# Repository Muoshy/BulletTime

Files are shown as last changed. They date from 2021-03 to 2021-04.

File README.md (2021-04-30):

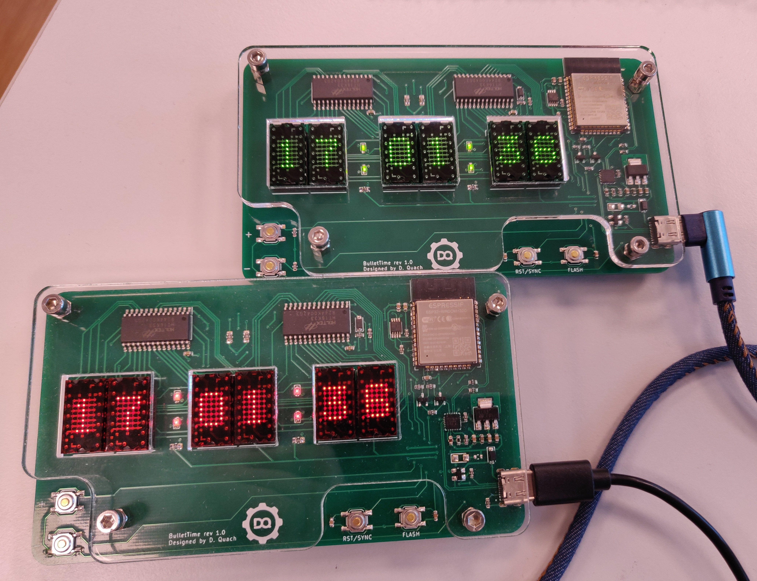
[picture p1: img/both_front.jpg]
top


# BulletTime
ESP32 based clock using LTP-305 led matrices.

	- NTP time retrieval
	- Brightness control
	- esp-idf
	- USB-C

## Schematic
WIP

## PCB
WIP

## Acrylic cover
WIP

## Software
Running esp-idf with esp32-wifi-manager 3.3.1 by tonyp7 for setting wifi credentials during runtime. 
Time set using sntp time example from esp-idf repository.
Brightness control using button interrupts.

## Flashing
	- Install esp-idf extension from Visual Studio Code marketplace
	- Open LTP_clock folder from VSCode
	- Select port, compile & flash.

## BOM

| Component 		| Quantity 	| Description 						|
|---		|---	|---								|
| ESP32-WROOM-32D 	| 1x 		| ESP32 						|
| CP2102N-A02-GQFN24 | 1x 	| USB-UART 						|
| HT16K33			| 2x		| LED driver |
| LDL1117 			| 1x 	| Voltage regulator 			|
| SP0503BAHTG				 	| 1x 	| ESD-protection 				|
| LTP-305					 	| 6x 	| 5x7 led matrix 				|
| PCA9306					 	| 1x 	| I2C level shifter 			|
| 5.2x5.2mm SMD pushbutton 		| 4x 	| Pushbutton						|
| 14 Position DIP socket | 6x 	| 								|
| Resistors (WIP) 		| 	| 								|
| Capacitors (WIP) 		| 	| 								|

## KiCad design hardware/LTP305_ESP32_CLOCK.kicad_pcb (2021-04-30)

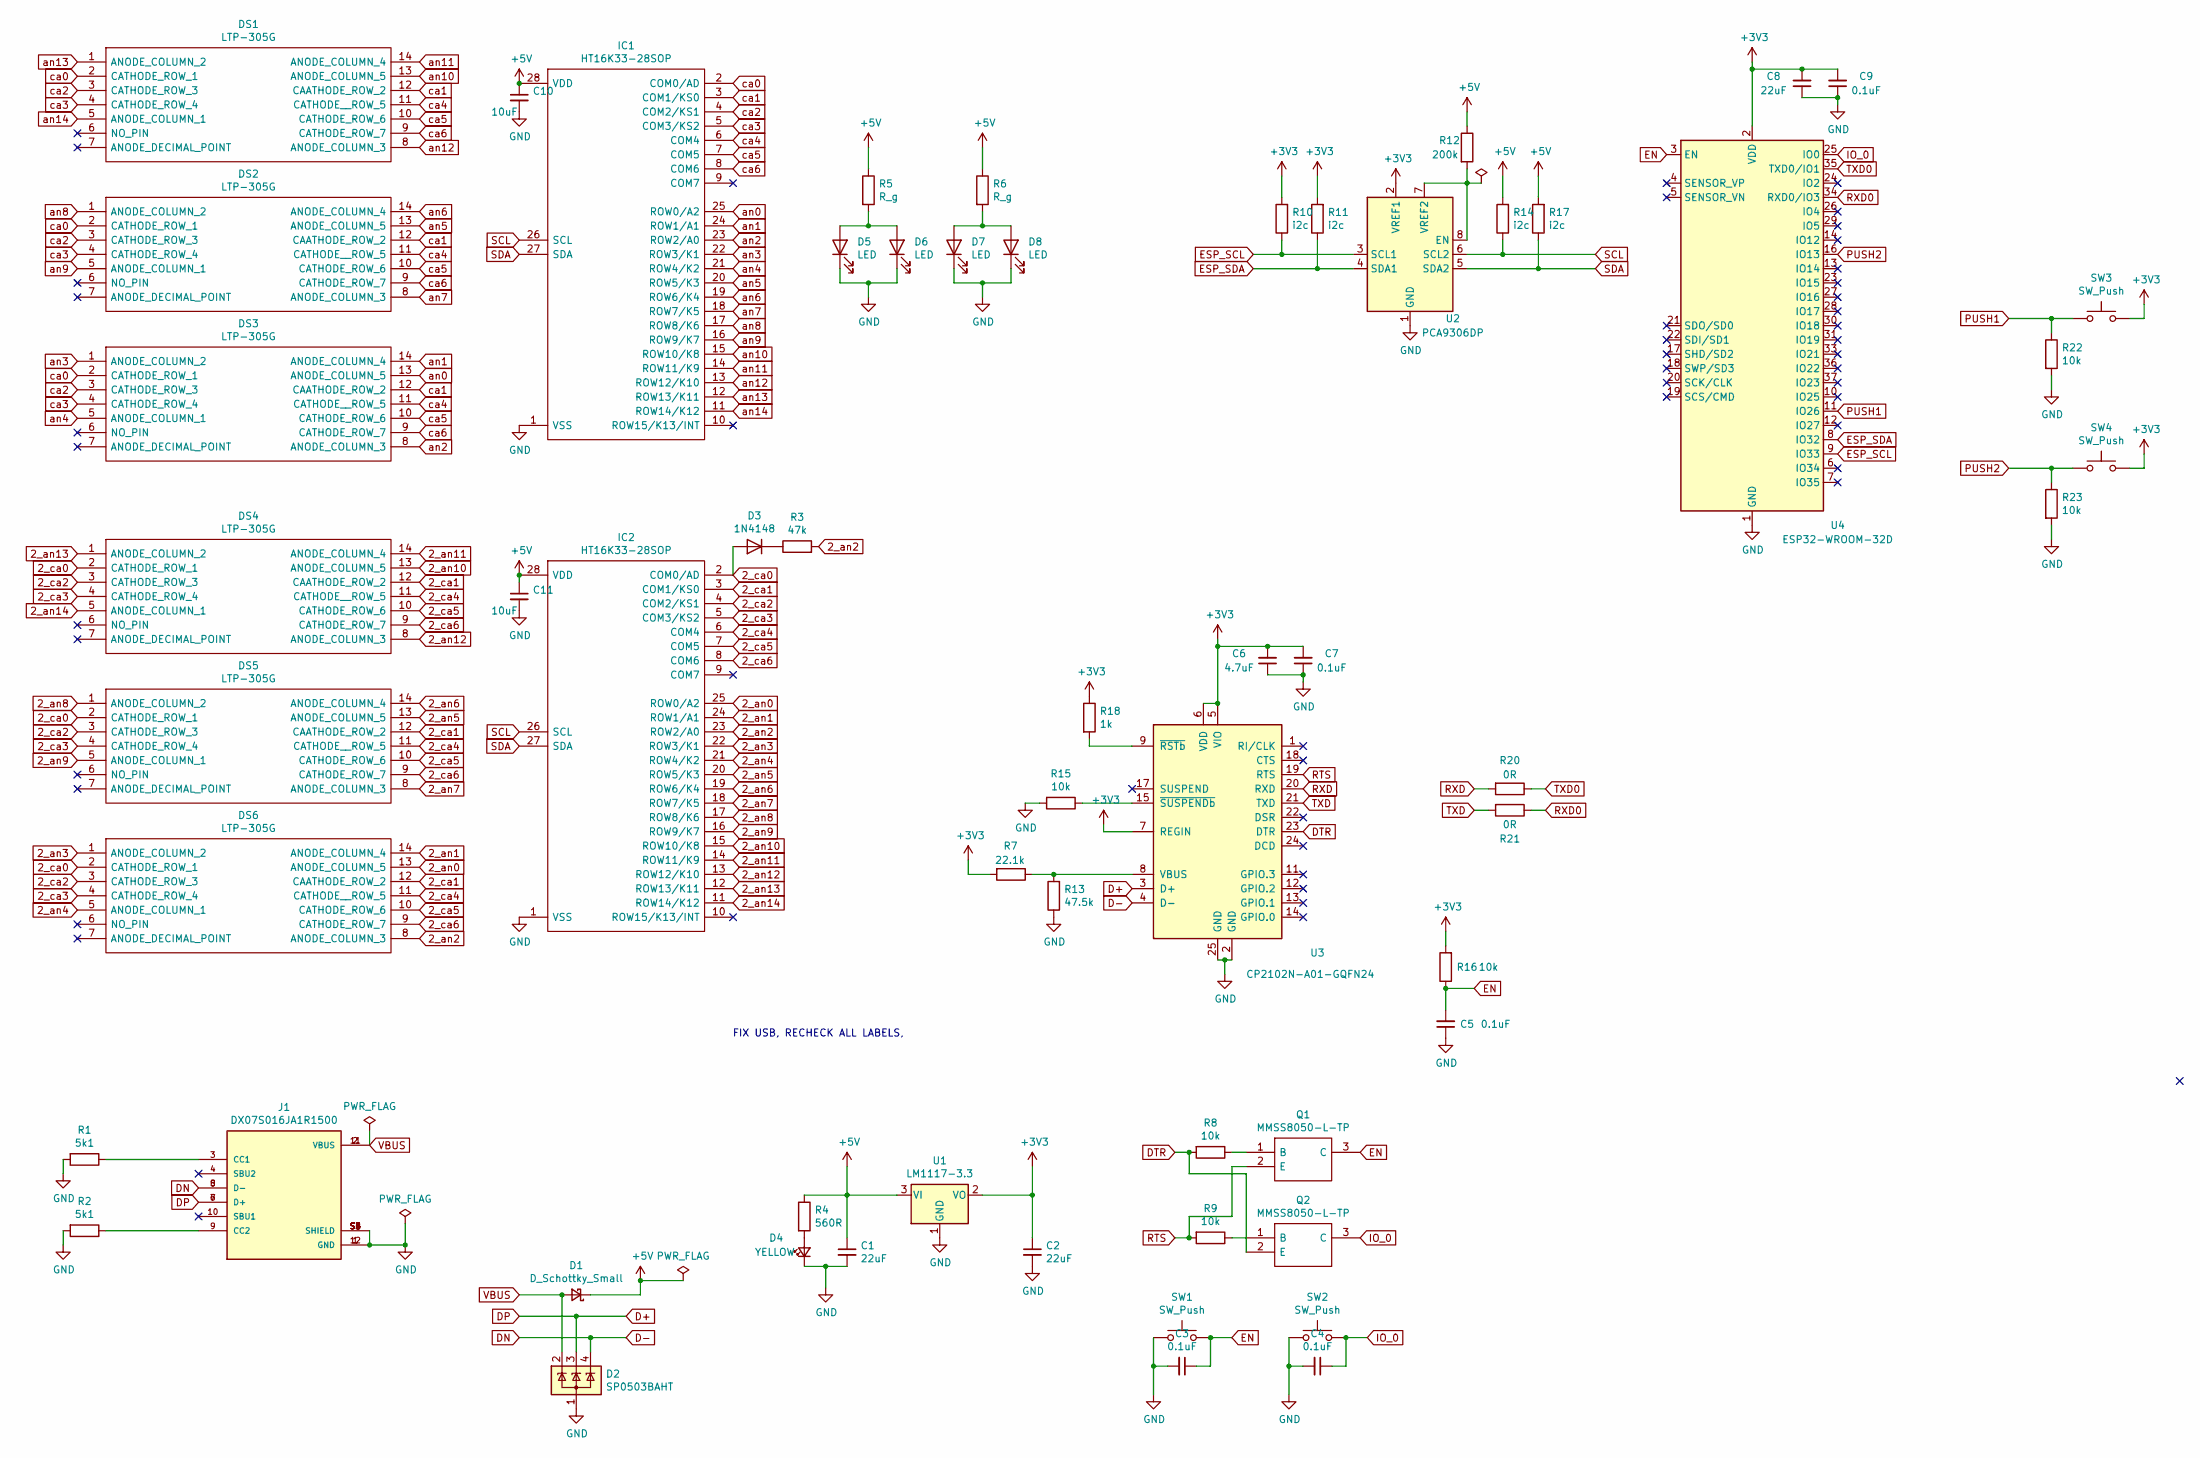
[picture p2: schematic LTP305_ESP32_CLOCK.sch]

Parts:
C1, C2, C8: 22uF; C_0603_1608Metric
C3, C4, C5, C7, C9: 0.1uF; C_0603_1608Metric
C6: 4.7uF; C_0603_1608Metric
C10, C11: 10uF; C_0603_1608Metric
D1: D_Schottky_Small; D_SOD-123
D2: SP0503BAHT; SOT-143
D3: 1N4148; D_SOD-123
D4: YELLOW; LED_1206_3216Metric_Castellated
D5, D6, D7, D8: LED; LED_0603_1608Metric_Pad1.05x0.95mm_HandSolder
DS1, DS2, DS3, DS4, DS5, DS6: LTP-305G; DIPS762W50P254L1850H400Q14N; Mouser Part Number 859-LTP-305G
IC1, IC2: HT16K33-28SOP; SOIC127P1031X264-28N; Manufacturer_Part_Number HT16K33-28SOP
J1: DX07S016JA1R1500; JAE_DX07S016JA1R1500; PARTREV 1
Q1, Q2: MMSS8050-L-TP; SOT96P237X122-3N; Mouser Part Number 833-MMSS8050-L-TP
R1, R2: 5k1; R_0603_1608Metric
R3: 47k; R_0603_1608Metric
R4: 560R; R_0603_1608Metric
R5, R6: R_g; R_0805_2012Metric_Pad1.20x1.40mm_HandSolder
R7: 22.1k; R_0603_1608Metric
R8, R9, R15, R16, R22, R23: 10k; R_0603_1608Metric
R10, R11: i2c; R_0603_1608Metric
R12: 200k; R_0603_1608Metric
R13: 47.5k; R_0603_1608Metric
R14, R17: i2c; R_0805_2012Metric_Pad1.20x1.40mm_HandSolder
R18: 1k; R_0603_1608Metric
R20, R21: 0R; R_0603_1608Metric
SW1, SW2, SW3, SW4: SW_Push; SW_SPST_SKQG_WithStem
U1: LM1117-3.3; SOT-223
U2: PCA9306DP; TSSOP-8_3x3mm_P0.65mm
U3: CP2102N-A01-GQFN24; QFN-24-1EP_4x4mm_P0.5mm_EP2.6x2.6mm
U4: ESP32-WROOM-32D; ESP32-WROOM-32

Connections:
2_an0: DS6.13 (ANODE_COLUMN_5), IC2.25 (ROW0/A2)
2_an1: DS6.14 (ANODE_COLUMN_4), IC2.24 (ROW1/A1)
2_an2: DS6.8 (ANODE_COLUMN_3), IC2.23 (ROW2/A0), R3.2
2_an3: DS6.1 (ANODE_COLUMN_2), IC2.22 (ROW3/K1)
2_an4: DS6.5 (ANODE_COLUMN_1), IC2.21 (ROW4/K2)
2_an5: DS5.13 (ANODE_COLUMN_5), IC2.20 (ROW5/K3)
2_an6: DS5.14 (ANODE_COLUMN_4), IC2.19 (ROW6/K4)
2_an7: DS5.8 (ANODE_COLUMN_3), IC2.18 (ROW7/K5)
2_an8: DS5.1 (ANODE_COLUMN_2), IC2.17 (ROW8/K6)
2_an9: DS5.5 (ANODE_COLUMN_1), IC2.16 (ROW9/K7)
2_an10: DS4.13 (ANODE_COLUMN_5), IC2.15 (ROW10/K8)
2_an11: DS4.14 (ANODE_COLUMN_4), IC2.14 (ROW11/K9)
2_an12: DS4.8 (ANODE_COLUMN_3), IC2.13 (ROW12/K10)
2_an13: DS4.1 (ANODE_COLUMN_2), IC2.12 (ROW13/K11)
2_an14: DS4.5 (ANODE_COLUMN_1), IC2.11 (ROW14/K12)
2_ca0: D3.2 (A), DS4.2 (CATHODE_ROW_1), DS5.2 (CATHODE_ROW_1), DS6.2 (CATHODE_ROW_1), IC2.2 (COM0/AD)
2_ca1: DS4.12 (CAATHODE_ROW_2), DS5.12 (CAATHODE_ROW_2), DS6.12 (CAATHODE_ROW_2), IC2.3 (COM1/KS0)
2_ca2: DS4.3 (CATHODE_ROW_3), DS5.3 (CATHODE_ROW_3), DS6.3 (CATHODE_ROW_3), IC2.4 (COM2/KS1)
2_ca3: DS4.4 (CATHODE_ROW_4), DS5.4 (CATHODE_ROW_4), DS6.4 (CATHODE_ROW_4), IC2.5 (COM3/KS2)
2_ca4: DS4.11 (CATHODE__ROW_5), DS5.11 (CATHODE__ROW_5), DS6.11 (CATHODE__ROW_5), IC2.6 (COM4)
2_ca5: DS4.10 (CATHODE_ROW_6), DS5.10 (CATHODE_ROW_6), DS6.10 (CATHODE_ROW_6), IC2.7 (COM5)
2_ca6: DS4.9 (CATHODE_ROW_7), DS5.9 (CATHODE_ROW_7), DS6.9 (CATHODE_ROW_7), IC2.8 (COM6)
+3V3: C2.1, C6.2, C7.2, C8.2, C9.2, R7.2, R10.2, R11.2, R16.2, R18.1, SW3.2, SW4.2, U1.2 (VO), U1.4, U2.2 (VREF1), U3.5 (VIO), U3.6 (VDD), U3.7 (REGIN), U4.2 (VDD); also elsewhere on the board
+5V: C1.1, C10.1, C11.1, D1.1 (K), IC1.28 (VDD), IC2.28 (VDD), R4.1, R5.1, R6.1, R12.1, R14.2, R17.2, U1.3 (VI)
D+: D2.3 (K), J1.6 (D+), J1.7 (D+), U3.3 (D+)
D-: D2.4 (K), J1.5 (D-), J1.8 (D-), U3.4 (D-)
DTR: Q2.2 (E), R8.2, U3.23 (DTR)
EN: C3.1, C5.2, Q1.3 (C), R16.1, SW1.2, U4.3 (EN); also elsewhere on the board
ESP_SCL: R10.1, U2.3 (SCL1), U4.9 (IO33)
ESP_SDA: R11.1, U2.4 (SDA1), U4.8 (IO32)
GND: C1.2, C2.2, C3.2, C4.2, C5.1, C6.1, C7.1, C8.1, C9.1, C10.2, C11.2, D2.1 (A), D4.1 (K), D5.1 (K), D6.1 (K), D7.1 (K), D8.1 (K), IC1.1 (VSS), IC2.1 (VSS), J1.1 (GND), J1.12 (GND), J1.S1 (SHIELD), J1.S2 (SHIELD), J1.S3 (SHIELD), J1.S4 (SHIELD), J1.S5 (SHIELD), J1.S6 (SHIELD), R1.2, R2.2, R13.1, R15.2, R22.2, R23.2, SW1.1, SW2.1, U1.1 (GND), U2.1 (GND), U3.2 (GND), U3.25 (GND), U4.1 (GND), U4.15 (GND), U4.38 (GND), U4.39 (GND); also elsewhere on the board
IO_0: C4.1, Q2.3 (C), SW2.2, U4.25 (IO0); also elsewhere on the board
unnamed: D3.1 (K), R3.1
unnamed: D4.2 (A), R4.2
unnamed: D5.2 (A), D6.2 (A), R5.2
unnamed: D7.2 (A), D8.2 (A), R6.2
unnamed: J1.3 (CC1), R1.1
unnamed: J1.9 (CC2), R2.1
unnamed: Q1.1 (B), R8.1
unnamed: Q2.1 (B), R9.1
unnamed: R12.2, U2.7 (VREF2), U2.8 (EN)
unnamed: R7.1, R13.2, U3.8 (VBUS)
unnamed: R15.1, U3.15 (~SUSPENDb)
unnamed: R18.2, U3.9 (~RSTb)
PUSH1: R22.1, SW3.1, U4.11 (IO26); also elsewhere on the board
PUSH2: R23.1, SW4.1, U4.16 (IO13); also elsewhere on the board
RTS: Q1.2 (E), R9.2, U3.19 (RTS)
RXD: R20.2, U3.20 (RXD)
RXD0: R21.1, U4.34 (RXD0/IO3)
SCL: IC1.26 (SCL), IC2.26 (SCL), R14.1, U2.6 (SCL2)
SDA: IC1.27 (SDA), IC2.27 (SDA), R17.1, U2.5 (SDA2)
TXD: R21.2, U3.21 (TXD)
TXD0: R20.1, U4.35 (TXD0/IO1)
VBUS: D1.2 (A), D2.2 (K), J1.2 (VBUS), J1.11 (VBUS)
an0: DS3.13 (ANODE_COLUMN_5), IC1.25 (ROW0/A2)
an1: DS3.14 (ANODE_COLUMN_4), IC1.24 (ROW1/A1)
an2: DS3.8 (ANODE_COLUMN_3), IC1.23 (ROW2/A0)
an3: DS3.1 (ANODE_COLUMN_2), IC1.22 (ROW3/K1)
an4: DS3.5 (ANODE_COLUMN_1), IC1.21 (ROW4/K2)
an5: DS2.13 (ANODE_COLUMN_5), IC1.20 (ROW5/K3)
an6: DS2.14 (ANODE_COLUMN_4), IC1.19 (ROW6/K4)
an7: DS2.8 (ANODE_COLUMN_3), IC1.18 (ROW7/K5)
an8: DS2.1 (ANODE_COLUMN_2), IC1.17 (ROW8/K6)
an9: DS2.5 (ANODE_COLUMN_1), IC1.16 (ROW9/K7)
an10: DS1.13 (ANODE_COLUMN_5), IC1.15 (ROW10/K8)
an11: DS1.14 (ANODE_COLUMN_4), IC1.14 (ROW11/K9)
an12: DS1.8 (ANODE_COLUMN_3), IC1.13 (ROW12/K10)
an13: DS1.1 (ANODE_COLUMN_2), IC1.12 (ROW13/K11)
an14: DS1.5 (ANODE_COLUMN_1), IC1.11 (ROW14/K12)
ca0: DS1.2 (CATHODE_ROW_1), DS2.2 (CATHODE_ROW_1), DS3.2 (CATHODE_ROW_1), IC1.2 (COM0/AD)
ca1: DS1.12 (CAATHODE_ROW_2), DS2.12 (CAATHODE_ROW_2), DS3.12 (CAATHODE_ROW_2), IC1.3 (COM1/KS0)
ca2: DS1.3 (CATHODE_ROW_3), DS2.3 (CATHODE_ROW_3), DS3.3 (CATHODE_ROW_3), IC1.4 (COM2/KS1)
ca3: DS1.4 (CATHODE_ROW_4), DS2.4 (CATHODE_ROW_4), DS3.4 (CATHODE_ROW_4), IC1.5 (COM3/KS2)
ca4: DS1.11 (CATHODE__ROW_5), DS2.11 (CATHODE__ROW_5), DS3.11 (CATHODE__ROW_5), IC1.6 (COM4)
ca5: DS1.10 (CATHODE_ROW_6), DS2.10 (CATHODE_ROW_6), DS3.10 (CATHODE_ROW_6), IC1.7 (COM5)
ca6: DS1.9 (CATHODE_ROW_7), DS2.9 (CATHODE_ROW_7), DS3.9 (CATHODE_ROW_7), IC1.8 (COM6)

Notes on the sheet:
FIX USB, RECHECK ALL LABELS,

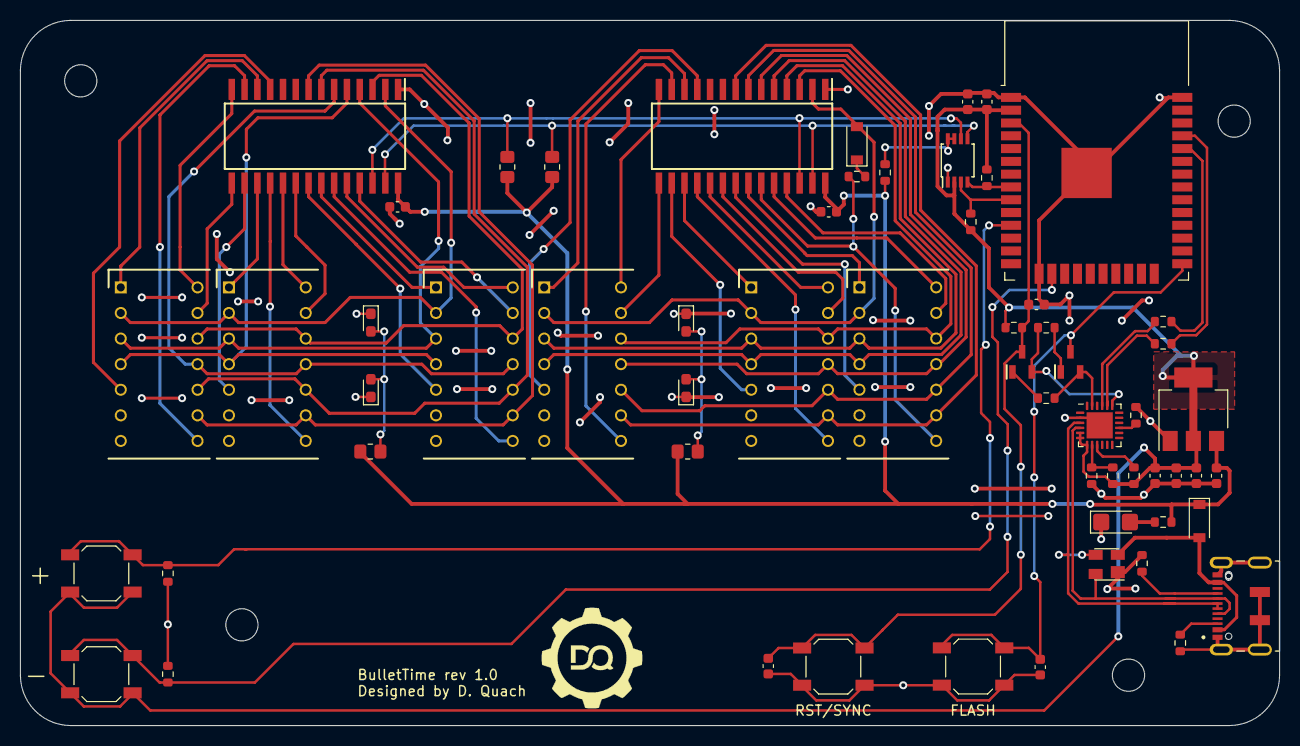
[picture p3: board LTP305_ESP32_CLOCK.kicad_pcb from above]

Board: 2 copper layers, 125.0 x 70.0 mm, 60 parts (0 on the bottom side), 76 nets.

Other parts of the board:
+: SW_Push; SW_SPST_SKQG_WithStem
-: SW_Push; SW_SPST_SKQG_WithStem
FLASH: SW_Push; SW_SPST_SKQG_WithStem
RST/SYNC: SW_Push; SW_SPST_SKQG_WithStem

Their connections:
+3V3: +.2, -.2; also elsewhere on the board
EN: RST/SYNC.2; also elsewhere on the board
GND: FLASH.1, RST/SYNC.1; also elsewhere on the board
IO_0: FLASH.2; also elsewhere on the board
PUSH1: +.1; also elsewhere on the board
PUSH2: -.1; also elsewhere on the board

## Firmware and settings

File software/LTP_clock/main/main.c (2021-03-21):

#include "esp_log.h"
#include "driver/i2c.h"
#include "sdkconfig.h"

#include "freertos/FreeRTOS.h"
#include "freertos/task.h"
#include "freertos/event_groups.h"
#include "esp_system.h"
#include "esp_event.h"
#include "esp_spi_flash.h"

#include <time.h>
#include <sys/time.h>
#include <esp_wifi.h>
#include <esp_netif.h>

#include "esp_sntp.h"
#include "wifi_manager.h"


#define TAG "i2c_bus"
#define ack_en false

#define GPIO_INPUT_IO_0     26
#define GPIO_INPUT_IO_1     13
#define GPIO_INPUT_PIN_SEL  ((1ULL<<GPIO_INPUT_IO_0) | (1ULL<<GPIO_INPUT_IO_1))
#define ESP_INTR_FLAG_DEFAULT 0

static uint8_t b = 5;
static uint8_t prevb = 5;

static xQueueHandle gpio_evt_queue = NULL;

static void IRAM_ATTR gpio_isr_handler(void* arg)
{
    uint32_t gpio_num = (uint32_t) arg;
    xQueueSendFromISR(gpio_evt_queue, &gpio_num, NULL);
}

static void gpio_task_example(void* arg)
{
    uint32_t io_num;
    for(;;) {
        if(xQueueReceive(gpio_evt_queue, &io_num, portMAX_DELAY)) {
            if(io_num == 26) {b++;}
            if(io_num == 13) {b--;}
            if(b>20) {b = 20;}
            if(b<1) {b = 1;}
            printf("GPIO[%d] intr, val: %d\n", io_num, gpio_get_level(io_num));
            printf("Brightness: %i \n", b);

        }
    }
}



const uint16_t digits[10][8] = {

{0x0E, 0x11, 0x11, 0x11, 0x11, 0x11, 0x0E, 0x00},

{0x04, 0x0C, 0x04, 0x04, 0x04, 0x04, 0x0E, 0x00},

{0x0E, 0x11, 0x11, 0x02, 0x04, 0x08, 0x1F, 0x00},

{0x1F, 0x02, 0x04, 0x0E, 0x01, 0x11, 0x0E, 0x00},

{0x02, 0x06, 0x0A, 0x12, 0x1F, 0x02, 0x02, 0x00}, 

{0x1F, 0x10, 0x10, 0x1E, 0x01, 0x01, 0x1E, 0x00},

{0x0E, 0x11, 0x10, 0x1E, 0x11, 0x11, 0x0E, 0x00},

{0x1F, 0x01, 0x02, 0x04, 0x04, 0x04, 0x04, 0x00},

{0x0E, 0x11, 0x11, 0x0E, 0x11, 0x11, 0x0E, 0x00},

{0x0E, 0x11, 0x11, 0x0F, 0x01, 0x11, 0x0E, 0x00}

};


void set_oscillator(uint8_t addr) {
    i2c_cmd_handle_t handle = i2c_cmd_link_create();
    i2c_master_start(handle);

    i2c_master_write_byte(handle, addr << 1 | I2C_MASTER_WRITE, ack_en);
    i2c_master_write_byte(handle, 0x20 | 1, ack_en);

    i2c_master_stop(handle);

    esp_err_t error = i2c_master_cmd_begin(I2C_NUM_0, handle, 1000 / portTICK_RATE_MS);
    if (error != ESP_OK) {
    ESP_LOGI(TAG, "Failed to set oscillator: %s", esp_err_to_name(error));
    }

    i2c_cmd_link_delete(handle);
}

void set_blink(uint8_t b, uint8_t addr){
	if(b > 3) return;
    i2c_cmd_handle_t handle = i2c_cmd_link_create();
    i2c_master_start(handle);
	i2c_master_write_byte(handle, addr << 1 | I2C_MASTER_WRITE, ack_en);
	i2c_master_write_byte(handle, 0x80 | b << 1 | 1, ack_en); // Blinking / blanking command
    i2c_master_stop(handle);

    esp_err_t error = i2c_master_cmd_begin(I2C_NUM_0, handle, 1000 / portTICK_RATE_MS);
    if (error != ESP_OK) {
    ESP_LOGI(TAG, "Failed to set blink mode: %s", esp_err_to_name(error));
    }

    i2c_cmd_link_delete(handle);	
}

void set_brightness(uint8_t b, uint8_t addr) {
    i2c_cmd_handle_t handle = i2c_cmd_link_create();
    i2c_master_start(handle);

    i2c_master_write_byte(handle, addr << 1 | I2C_MASTER_WRITE, ack_en);
    i2c_master_write_byte(handle, 0xE0 | b , ack_en);

    i2c_master_stop(handle);

    esp_err_t error = i2c_master_cmd_begin(I2C_NUM_0, handle, 1000 / portTICK_RATE_MS);
    if (error != ESP_OK) {
    ESP_LOGI(TAG, "Failed to set brightness: %s", esp_err_to_name(error));
    }

    i2c_cmd_link_delete(handle);	
}

void clear_matrix(uint8_t addr) {
    i2c_cmd_handle_t handle = i2c_cmd_link_create();
    i2c_master_start(handle);
    i2c_master_write_byte(handle, addr << 1 | I2C_MASTER_WRITE, ack_en);
    i2c_master_write_byte(handle, 0x00, ack_en);

    for(int i = 0; i < 16; i++) {
            i2c_master_write_byte(handle, 0x00, ack_en);
        }

    i2c_master_stop(handle);

    esp_err_t error = i2c_master_cmd_begin(I2C_NUM_0, handle, 1000 / portTICK_RATE_MS);
    if (error != ESP_OK) {
    ESP_LOGI(TAG, "Failed to clear matrix: %s", esp_err_to_name(error));
    }

    i2c_cmd_link_delete(handle);
}

void time_sync_notification_cb(struct timeval *tv)
{
    ESP_LOGI(TAG, "Notification of a time synchronization event");
}


static void initialize_sntp(void)
{
    ESP_LOGI(TAG, "Initializing SNTP");
    sntp_setoperatingmode(SNTP_OPMODE_POLL);
    sntp_setservername(0, "pool.ntp.org");
    sntp_set_time_sync_notification_cb(time_sync_notification_cb);
    sntp_init();
}

static void obtain_time(void)
{

    initialize_sntp();

    // wait for time to be set
    time_t now = 0;
    struct tm timeinfo = { 0 };
    int retry = 0;
    const int retry_count = 10;
    while (sntp_get_sync_status() == SNTP_SYNC_STATUS_RESET && ++retry < retry_count) {
        ESP_LOGI(TAG, "Waiting for system time to be set... (%d/%d)", retry, retry_count);
        vTaskDelay(2000 / portTICK_PERIOD_MS);
    }
    time(&now);
    localtime_r(&now, &timeinfo);

}



void cb_connection_ok(){

    vTaskDelay( pdMS_TO_TICKS(500) );

    time_t now;
    struct tm timeinfo;
    time(&now);
    localtime_r(&now, &timeinfo);

    obtain_time();
    time(&now);

    char strftime_buf[64];

    setenv("TZ", "CET-1CEST,M3.5.0,M10.5.0/3", 1);
    tzset();
    localtime_r(&now, &timeinfo);
    strftime(strftime_buf, sizeof(strftime_buf), "%c", &timeinfo);
    ESP_LOGI(TAG, "The current date/time in Stockholm is: %s", strftime_buf);

    wifi_manager_send_message(WM_ORDER_DISCONNECT_STA, NULL);
    
}


void print_task() {
	uint8_t prev_sec = 10;
    char ss[3];
    char mm[3];
    char hh[3];
    time_t now;
    struct tm timeinfo;

    uint8_t s1, s2, m1, m2, h1, h2;

    for(;;){

        time(&now);
        //char strftime_buf[64];

        localtime_r(&now, &timeinfo);
        //strftime(strftime_buf, sizeof(strftime_buf), "%c", &timeinfo);
        //ESP_LOGI(TAG, "The current date/time in Stockholm is: %s", strftime_buf);

        strftime(ss, 3, "%S", &timeinfo);
        strftime(mm, 3, "%M", &timeinfo);
        strftime(hh, 3, "%H", &timeinfo);

        s1 = ss[0] - '0';
        s2 = ss[1] - '0';

        m1 = mm[0] - '0';
        m2 = mm[1] - '0';

        h1 = hh[0] - '0';
        h2 = hh[1] - '0';

        if(s2 != prev_sec) {
            i2c_cmd_handle_t handle = i2c_cmd_link_create();
            i2c_master_start(handle);
            i2c_master_write_byte(handle, 0x70 << 1 | I2C_MASTER_WRITE, ack_en);
            i2c_master_write_byte(handle, 0x00, ack_en);
            for(int i = 0; i < 8; i++) {
                uint16_t row = (digits[h1][i] << 10) + (digits[h2][i] << 5) + digits[m1][i];
                i2c_master_write_byte(handle, row & 0xFF, ack_en);
                i2c_master_write_byte(handle, row >> 8, ack_en);
            }
            i2c_master_stop(handle);

            i2c_master_cmd_begin(I2C_NUM_0, handle, 1000 / portTICK_RATE_MS);
            i2c_cmd_link_delete(handle);

            handle = i2c_cmd_link_create();
            i2c_master_start(handle);
            i2c_master_write_byte(handle, 0x71 << 1 | I2C_MASTER_WRITE, ack_en);
            i2c_master_write_byte(handle, 0x00, ack_en);
            for(int i = 0; i < 8; i++) {
                uint16_t row = (digits[m2][i] << 10) + (digits[s1][i] << 5) + digits[s2][i];
                i2c_master_write_byte(handle, row & 0xFF, ack_en);
                i2c_master_write_byte(handle, row >> 8, ack_en);
            }
            i2c_master_stop(handle);

            i2c_master_cmd_begin(I2C_NUM_0, handle, 1000 / portTICK_RATE_MS);
            i2c_cmd_link_delete(handle);
            prev_sec = s2;
        }

        if(b != prevb) {
            set_brightness(b, 0x70);
            set_brightness(b, 0x71);
            prevb = b;
        }

		vTaskDelay( pdMS_TO_TICKS(100) );
	}

}

void cb_disconnect(){
    ESP_LOGI(TAG, "Disconnected from WiFi");
    xTaskCreatePinnedToCore(&print_task, "print_task", 2048, NULL, 1, NULL, 1);
	esp_wifi_stop();
	wifi_manager_destroy();
}


void app_main(void)
{   

    //------------ interrupt config
    gpio_config_t io_conf;

    io_conf.pull_down_en = 0;

    io_conf.pull_up_en = 0;

    io_conf.intr_type = GPIO_INTR_POSEDGE;

    io_conf.pin_bit_mask = GPIO_INPUT_PIN_SEL;

    io_conf.mode = GPIO_MODE_INPUT;
    
    gpio_config(&io_conf);

    gpio_evt_queue = xQueueCreate(10, sizeof(uint32_t));

    xTaskCreate(gpio_task_example, "gpio_task_example", 2048, NULL, 10, NULL);

    gpio_install_isr_service(ESP_INTR_FLAG_DEFAULT);

    gpio_isr_handler_add(GPIO_INPUT_IO_0, gpio_isr_handler, (void*) GPIO_INPUT_IO_0);

    gpio_isr_handler_add(GPIO_INPUT_IO_1, gpio_isr_handler, (void*) GPIO_INPUT_IO_1);

    //------------ i2c config
    i2c_config_t config;
    config.sda_io_num = 32;
    config.sda_pullup_en = GPIO_PULLUP_ENABLE;
    config.scl_io_num = 33;
    config.scl_pullup_en = GPIO_PULLUP_ENABLE;
    config.mode = I2C_MODE_MASTER;
    config.master.clk_speed = 40000;

    esp_err_t error = i2c_param_config(I2C_NUM_0, &config);
        if (error != ESP_OK) {
            ESP_LOGI(TAG, "Failed to configure shared i2c bus: %s", esp_err_to_name(error));
            return;
        }

    error = i2c_set_timeout(I2C_NUM_0, 100000);
        if (error != ESP_OK) {
            ESP_LOGI(TAG, "Failed set timeout for i2c bus: %s", esp_err_to_name(error));
            return;
        }


    error = i2c_driver_install(I2C_NUM_0, config.mode, 512, 512, 0);
        if (error != ESP_OK) {
            ESP_LOGI(TAG, "Failed to install driver for i2c bus: %s", esp_err_to_name(error));
        }

        
    set_oscillator(0x70);
    set_oscillator(0x71);

    set_brightness(5, 0x70);
    set_brightness(5, 0x71);

    set_blink(0, 0x70);
    set_blink(0, 0x71);

    clear_matrix(0x70);
    clear_matrix(0x71);

    wifi_manager_start();

    
    //wifi_manager_set_callback(WM_EVENT_STA_GOT_IP, &cb_connection_ok);
    wifi_manager_set_callback(WM_EVENT_STA_GOT_IP, &cb_connection_ok);

    wifi_manager_set_callback(WM_EVENT_STA_DISCONNECTED, &cb_disconnect);

}
